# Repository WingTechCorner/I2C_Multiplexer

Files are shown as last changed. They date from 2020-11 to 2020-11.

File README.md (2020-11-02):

# Wing's I2C Multiplexer

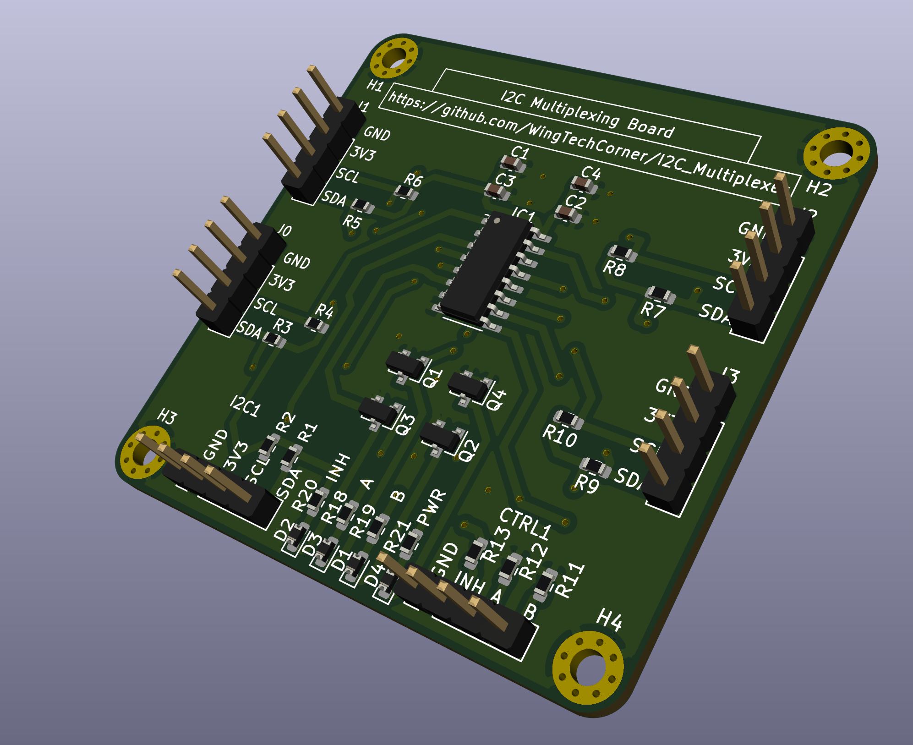
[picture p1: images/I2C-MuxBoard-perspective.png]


- Multiple I2C devices with the same address on the same bus.
- Not full duplex. Only one device active at any one time.
- Performs MUX'ing via 4052D IC

# Files/Folders

- `platformio.ini` PlatformIO project config file
- `./src/` Source code
- `./hardware/` Various hardware design files.

# Datasheets

- 4052D Dual 4-Channel Analog Multiplexer, Demultiplexer
  - [Nexperia 74HC4052D Datasheet from LCSC](https://datasheet.lcsc.com/szlcsc/Nexperia-74HC4052D-653_C11350.pdf)

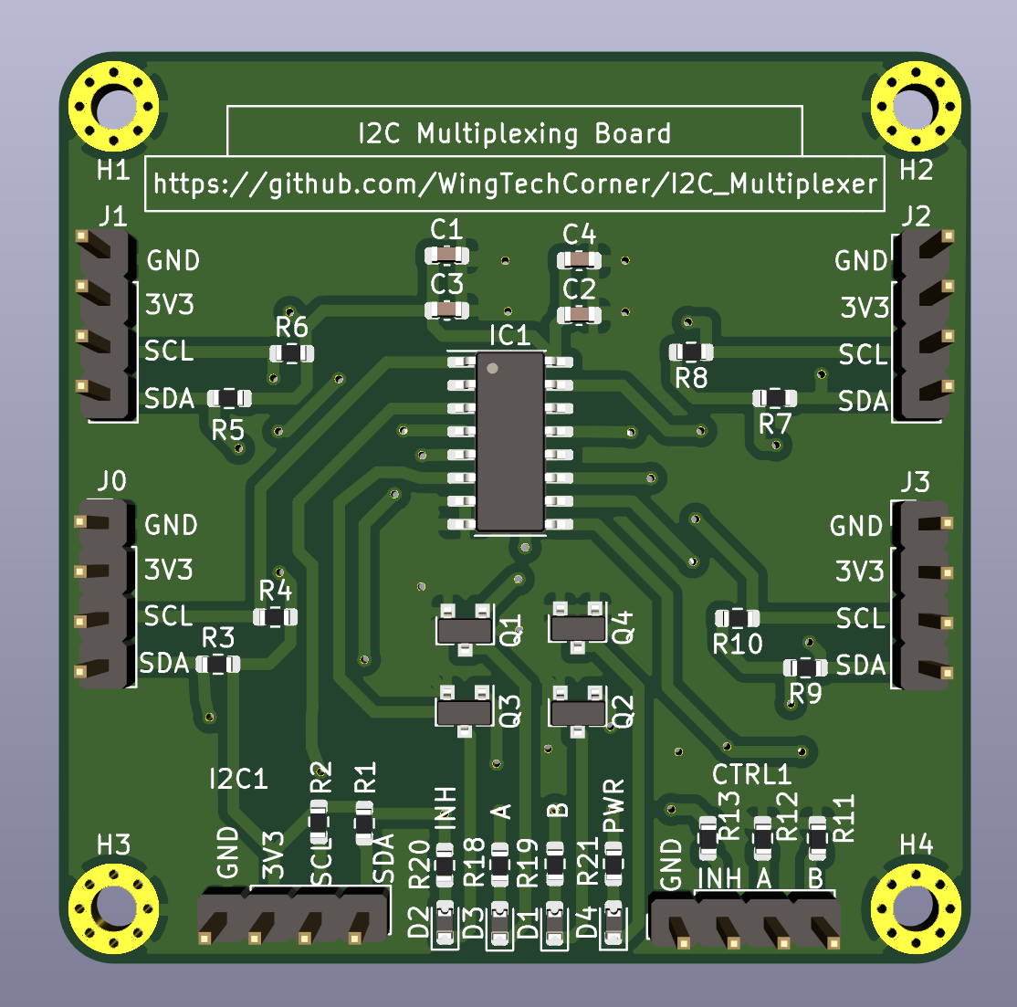
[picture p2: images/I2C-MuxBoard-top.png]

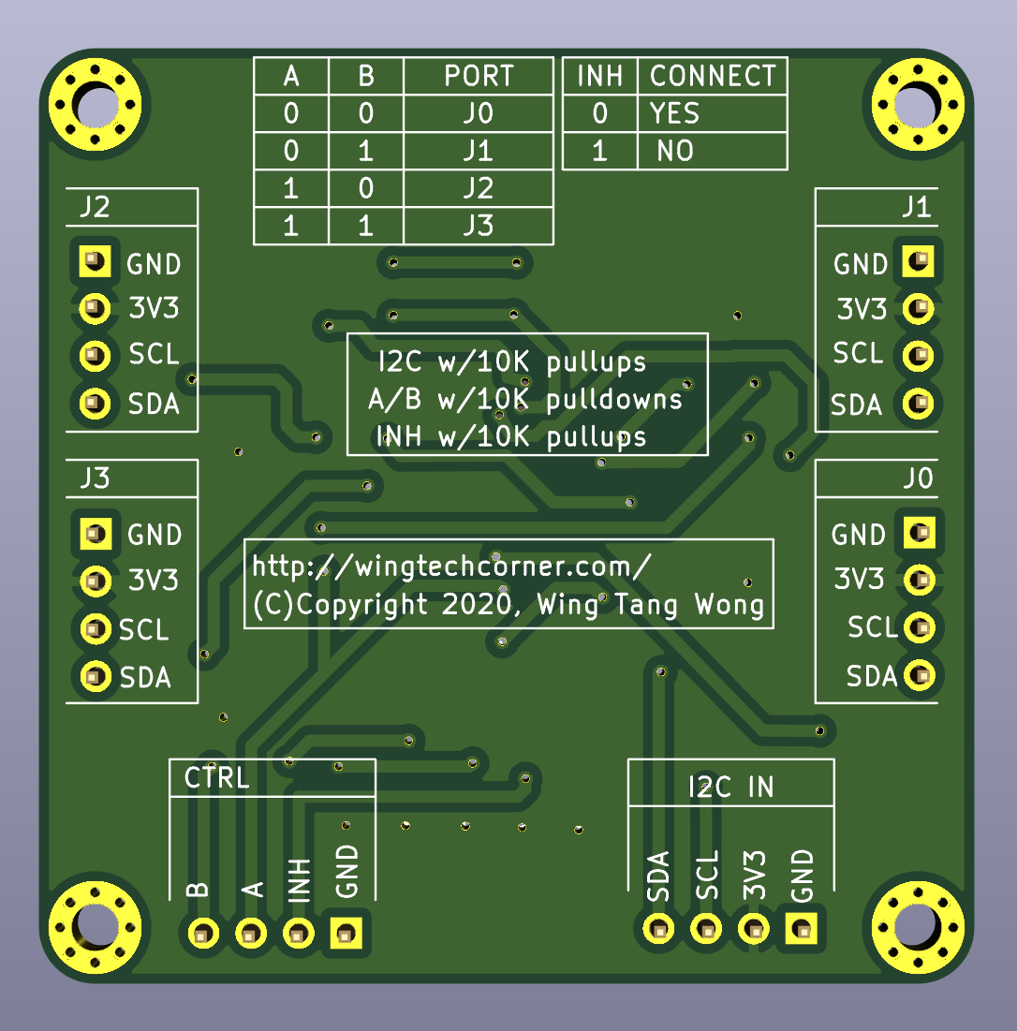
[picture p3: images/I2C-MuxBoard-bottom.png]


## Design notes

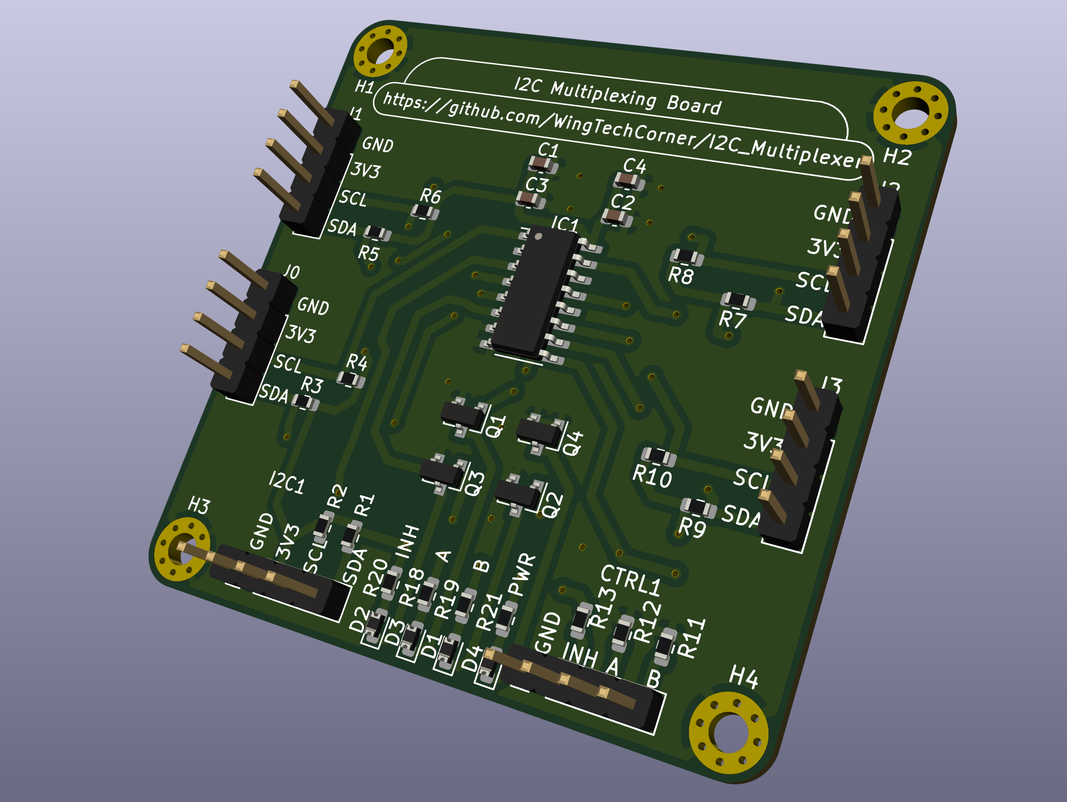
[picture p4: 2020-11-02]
images/orig/I2C-MuxBoard.png

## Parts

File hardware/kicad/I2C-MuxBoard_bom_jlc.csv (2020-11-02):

Comment | Designator | Footprint | LCSC Part #
4.7nF-50V-0603 | C1,C3 | C_0603_1608Metric | C53987
10nF-50V-0603 | C2,C4 | C_0603_1608Metric | C57112
BLUE_LED | D1,D3,D2,D4 | D_0603_1608Metric | C72041
CD4052B | IC1 | SOIC-16_3.9x9.9mm_P1.27mm | C6521
AO3400A | Q2,Q3,Q1,Q4 | SOT-23 | C20917
10KOhms-±1%-1_10W-0603 | R3,R4,R5,R6,R7,R8,R9,R10,R11,R12,R13,R1,R2 | R_0603_1608Metric | C25804
470Ohms-±1%-1_10W-0603 | R19,R18,R20,R21 | R_0603_1608Metric | C23179

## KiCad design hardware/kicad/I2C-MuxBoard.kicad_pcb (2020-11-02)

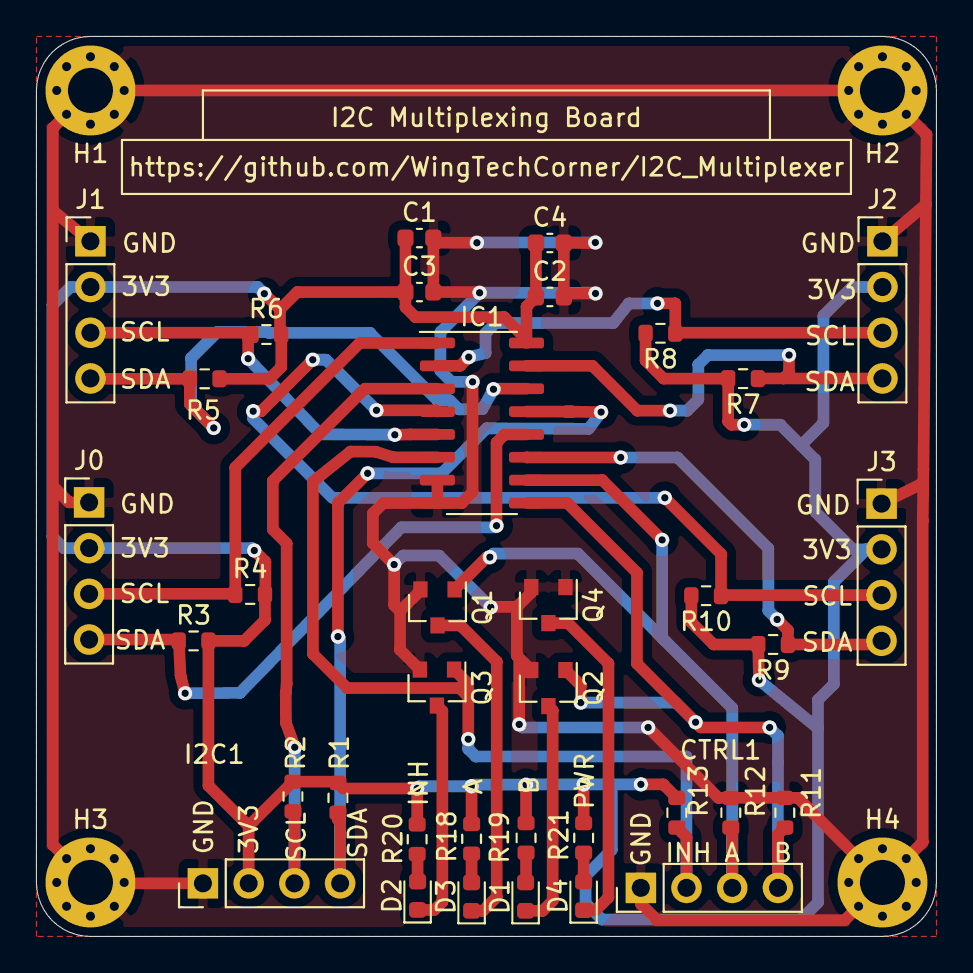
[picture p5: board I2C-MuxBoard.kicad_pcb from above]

Board: 2 copper layers, 50.0 x 50.0 mm, 40 parts (0 on the bottom side), 23 nets.

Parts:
C1, C3: 4.7nF-50V-0603; C_0603_1608Metric
C2, C4: 10nF-50V-0603; C_0603_1608Metric
CTRL1: Conn_01x04; PinHeader_1x04_P2.54mm_Vertical
D1, D2, D3, D4: BLUE_LED; D_0603_1608Metric
H1, H2, H3, H4: MountingHole_Pad; MountingHole_2.5mm_Pad_Via
I2C1: Conn_01x04; PinHeader_1x04_P2.54mm_Vertical
IC1: CD4052B; SOIC-16_3.9x9.9mm_P1.27mm
J0, J1, J2, J3: Conn_01x04; PinHeader_1x04_P2.54mm_Vertical
Q1, Q2, Q3, Q4: AO3400A; SOT-23
R1, R2, R3, R4, R5, R6, R7, R8, R9, R10, R11, R12, R13: 10KOhms-±1%-1_10W-0603; R_0603_1608Metric
R18, R19, R20, R21: 470Ohms-±1%-1_10W-0603; R_0603_1608Metric

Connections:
3V3: C1.1, C2.1, C3.1, C4.1, I2C1.2, IC1.16, J0.2, J1.2, J2.2, J3.2, R1.2, R2.2, R3.2, R4.2, R5.2, R6.2, R7.2, R8.2, R9.2, R10.2, R13.2, R18.1, R19.1, R20.1, R21.1
ADDR-A: CTRL1.3, IC1.10, Q1.1, R12.1
ADDR-B: CTRL1.4, IC1.9, Q2.1, R11.1
GND: C1.2, C2.2, C3.2, C4.2, CTRL1.1, H1.1, H2.1, H3.1, H4.1, I2C1.1, IC1.7, IC1.8, J0.1, J1.1, J2.1, J3.1, Q1.2, Q2.2, Q3.2, Q4.1, Q4.2, R11.2, R12.2
INH: CTRL1.2, IC1.6, Q3.1, R13.1
unnamed: D1.1, Q2.3
unnamed: D1.2, R19.2
unnamed: D2.1, Q3.3
unnamed: D2.2, R20.2
unnamed: D3.1, Q1.3
unnamed: D3.2, R18.2
unnamed: D4.1, Q4.3
unnamed: D4.2, R21.2
P0-SCL: IC1.1, J0.3, R4.1
P0-SDA: IC1.12, J0.4, R3.1
P1-SCL: IC1.5, J1.3, R6.1
P1-SDA: IC1.14, J1.4, R5.1
P2-SCL: IC1.2, J2.3, R8.1
P2-SDA: IC1.15, J2.4, R7.1
P3-SCL: IC1.4, J3.3, R10.1
P3-SDA: IC1.11, J3.4, R9.1
SCL: I2C1.3, IC1.3, R2.1
SDA: I2C1.4, IC1.13, R1.1

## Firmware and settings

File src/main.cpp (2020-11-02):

#include <Arduino.h>
#include <Wire.h>
#include <Adafruit_I2CDevice.h>
#include <Adafruit_GFX.h>
#include <Adafruit_SSD1306.h>

// For the MUX board
#define MUX_INH PB1
#define MUX_A PB0
#define MUX_B PA7

Adafruit_SSD1306 display[4];

void select_display(int d) {
  bool junk;
  junk=display[d].getPixel(1,1);
  if ( junk == true ) { junk = false; };
  if ( d == 0 ) {
    digitalWrite(MUX_INH,HIGH);
    digitalWrite(MUX_A,HIGH);
    digitalWrite(MUX_B,HIGH);
    digitalWrite(MUX_INH,LOW);
  };
  if ( d == 1 ) {
    digitalWrite(MUX_INH,HIGH);
    digitalWrite(MUX_A,HIGH);
    digitalWrite(MUX_B,LOW);
    digitalWrite(MUX_INH,LOW);
  };
  if ( d == 2 ) {
    digitalWrite(MUX_INH,HIGH);
    digitalWrite(MUX_A,LOW);
    digitalWrite(MUX_B,HIGH);
    digitalWrite(MUX_INH,LOW);
  };
  if ( d == 3 ) {
    digitalWrite(MUX_INH,HIGH);
    digitalWrite(MUX_A,LOW);
    digitalWrite(MUX_B,LOW);
    digitalWrite(MUX_INH,LOW);
  };


};


void draw_noise( int d ) {
  select_display(d);
  delay(50);
  bool junk;

  for(int i=0; i<=128; i++) {
    display[d].drawPixel(random(0,127), random(0,64), INVERSE);
  };

  display[d].display();

  if ( junk ) { junk = true; } else { junk = false; };
};


void setup() {
  Wire.begin();
  Serial.begin(115200);
  Serial.println("System started up.");

  pinMode(PC13,OUTPUT);
  pinMode(MUX_INH,OUTPUT);
  pinMode(MUX_A,OUTPUT);
  pinMode(MUX_B,OUTPUT);

  digitalWrite(MUX_INH,LOW);
  digitalWrite(MUX_A,HIGH);
  digitalWrite(MUX_B,HIGH);

  //display.begin(SSD1306_EXTERNALVCC, 0x3D); // Address 0x3C for 128x32
  Serial.println("> Settingup displays...");
  for(int ad=0; ad <=3; ad++) {
    select_display(ad);
    display[ad] = Adafruit_SSD1306(128, 64, &Wire);
    display[ad].begin(SSD1306_SWITCHCAPVCC, 0x3C); // Address 0x3C for 128x32
    display[ad].display();
    display[ad].clearDisplay();
    display[ad].display();
  };

}

void loop() {
  Serial.println("> Doing displays");
  for(int ad=0; ad <=3; ad++) {
    select_display(ad);
    Serial.print("Display: ");
    Serial.println(ad);
    draw_noise(ad);
  };
}

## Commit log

2020-11-02 Adding KiCad design files, GERBER files, BOM, and CPL files.
    [I2C-MuxBoard.csv, I2C-MuxBoard.kicad_pcb, I2C-MuxBoard.sch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]
2020-11-02 Updated main.cpp to remove unused variables, and changed delays to I2C get to work around cases of buffered I2C commands that get garbled if I2C bus switched before completion.
2020-11-02 Updated example main.cpp. Moved I2C getPixel into selection routine. Changed DrawPixel to INVERSE and not just WHITE or BLACK.

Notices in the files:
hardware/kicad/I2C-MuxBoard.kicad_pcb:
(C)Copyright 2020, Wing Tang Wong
